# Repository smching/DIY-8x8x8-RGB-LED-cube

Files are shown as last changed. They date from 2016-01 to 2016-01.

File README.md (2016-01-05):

# DIY 8x8x8 RGB LED cube

DIY 8x8x8 RGB LED cube

Thank you my friend Siew Goh Chuang, he made this beautiful LED cube:  This is a 8x8x8 RGB LED cube project, a modified version of the LED cube which originally designed by Kavindarrah:

http://www.kevindarrah.com

This project only modified the hardware but leaving the software (source code) intact. All the source code is available in Kavindarrah's website.

Documentation is available at  http://ediy.com.my/index.php/projects/item/135-diy-8x8x8-rgb-led-cube

Flickr album: https://www.flickr.com/photos/ediy2u/albums/72157663117824245

Youtube video: https://youtu.be/O3SzMkJ8tPI

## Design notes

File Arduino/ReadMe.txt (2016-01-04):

**Arduino Code**

These Arduino code were written by Kevin Darrah: http://www.kevindarrah.com/?cat=99

Revision Notes:
Rev 7 ¨C First released code.  This is what you see running in the demo video, and all the tutorial videos

Rev 11 ¨C Fixed a bug in the Bit Angle Modulation, See the video How it Really Works for more information

Rev 12 ¨C Fixed the Bitwise Operation to set pins LOW.  I was doing it PORTX &= 0<<pinNumber, it should be PORTX &= ~(1<<pinNumber)  The wrong way was ANDing every pin in the port with 0, where is the new way ANDs only the pin you want to turn OFF with 0 and the rest with 1.

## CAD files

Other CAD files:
Layer building tool.dwg
RGB LED CUBE COVER.dwg

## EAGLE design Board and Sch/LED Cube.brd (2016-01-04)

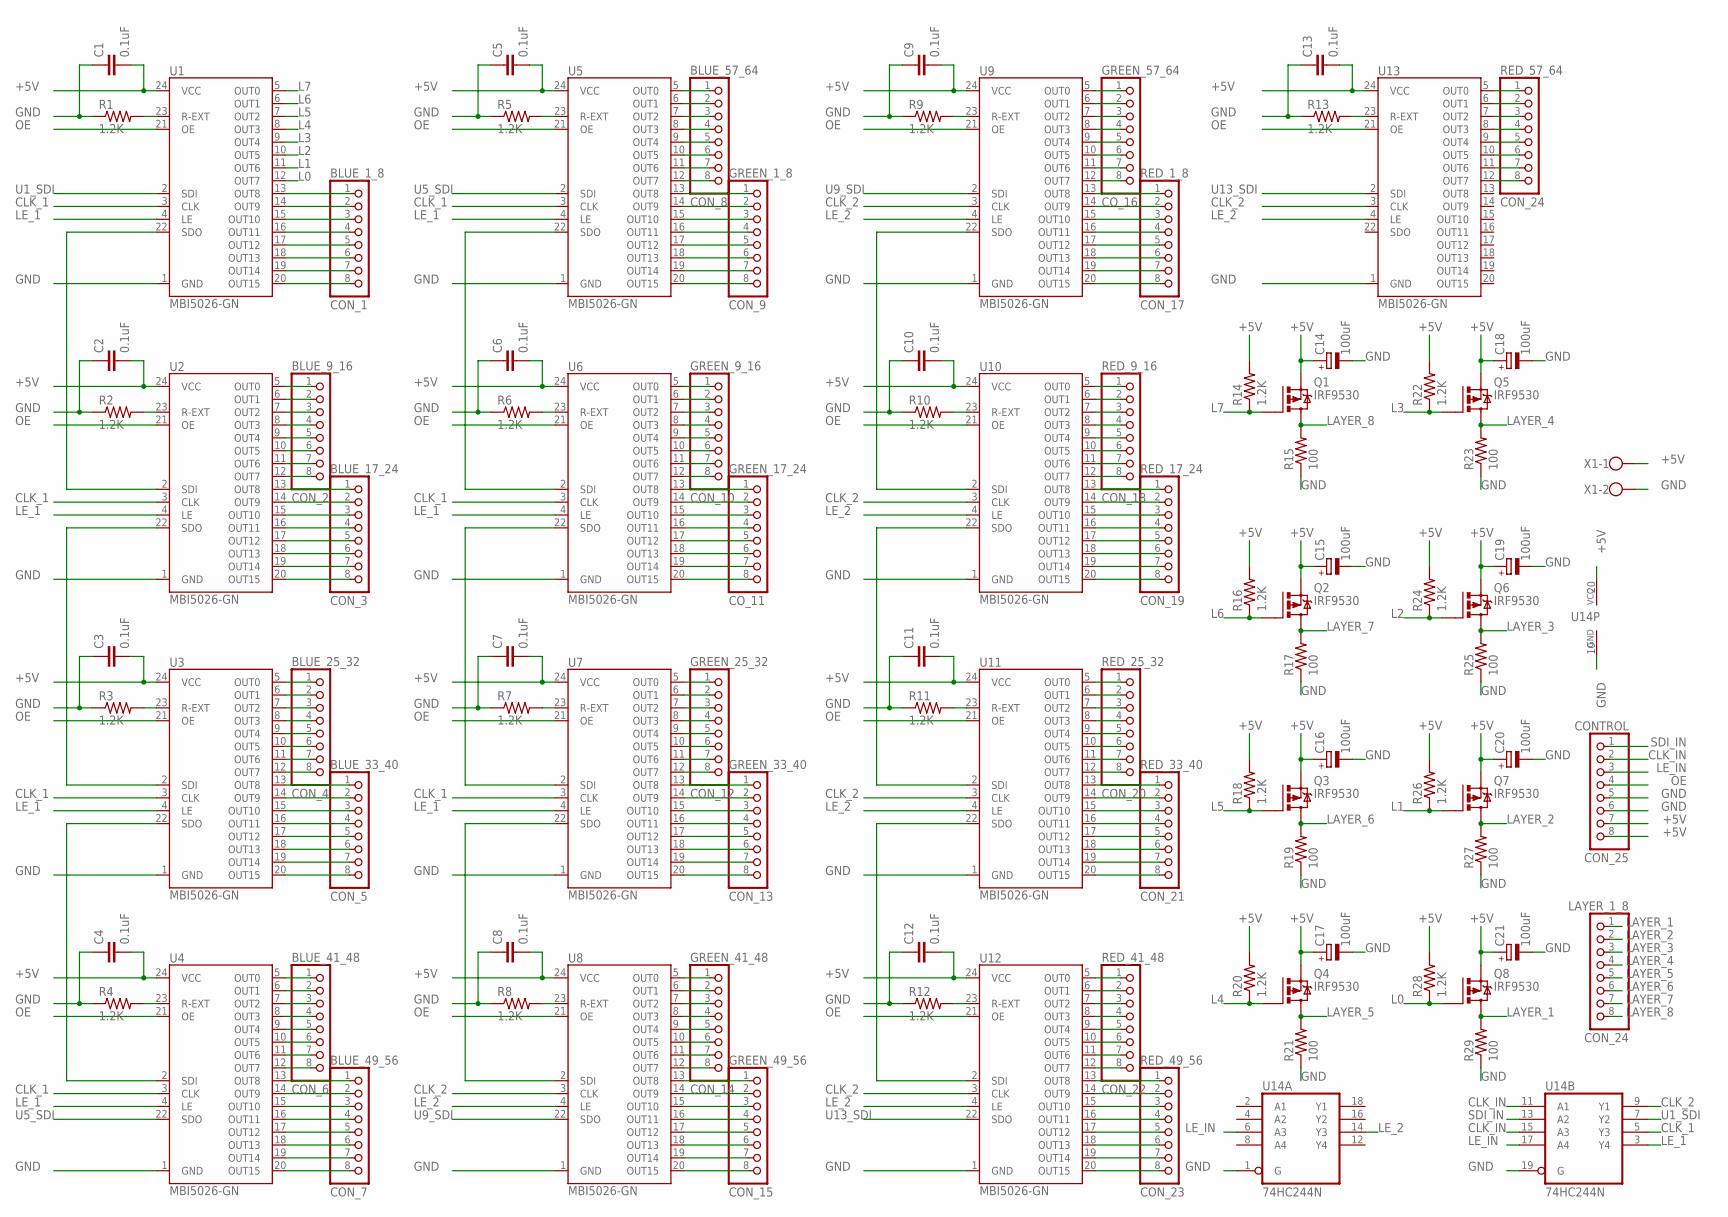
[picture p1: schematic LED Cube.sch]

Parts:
BLUE_1_8: CON_1; 1X08-BIG
BLUE_9_16: CON_2; 1X08-BIG
BLUE_17_24: CON_3; 1X08-BIG
BLUE_25_32: CON_4; 1X08-BIG
BLUE_33_40: CON_5; 1X08-BIG
BLUE_41_48: CON_6; 1X08-BIG
BLUE_49_56: CON_7; 1X08-BIG
BLUE_57_64: CON_8; 1X08-BIG
C1, C2, C3, C4, C5, C6, C7, C8, C9, C10, C11, C12, C13: 0.1uF; C2.5-3
C14, C15, C16, C17, C18, C19, C20, C21: 100uF; E5-6
CONTROL: CON_25; 1X08-BIG
GREEN_1_8: CON_9; 1X08-BIG
GREEN_9_16: CON_10; 1X08-BIG
GREEN_17_24: CO_11; 1X08-BIG
GREEN_25_32: CON_12; 1X08-BIG
GREEN_33_40: CON_13; 1X08-BIG
GREEN_41_48: CON_14; 1X08-BIG
GREEN_49_56: CON_15; 1X08-BIG
GREEN_57_64: CO_16; 1X08-BIG
LAYER_1_8: CON_24; 1X08-BIG
Q1, Q2, Q3, Q4, Q5, Q6, Q7, Q8: IRF9530; TO220BV
R1, R2, R3, R4, R5, R6, R7, R8, R9, R10, R11, R12, R13, R14, R16, R18, R20, R22, R24, R26, R28: 1.2K; 0207/15
R15, R17, R19, R21, R23, R25, R27, R29: 100; 0207/15
RED_1_8: CON_17; 1X08-BIG
RED_9_16: CON_18; 1X08-BIG
RED_17_24: CON_19; 1X08-BIG
RED_25_32: CON_20; 1X08-BIG
RED_33_40: CON_21; 1X08-BIG
RED_41_48: CON_22; 1X08-BIG
RED_49_56: CON_23; 1X08-BIG
RED_57_64: CON_24; 1X08-BIG
U1, U2, U3, U4, U5, U6, U7, U8, U9, U10, U11, U12, U13: MBI5026-GN; DIL24-3
U14: 74HC244N; DIL20
X1: W237-102

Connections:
+5V: C1.2, C2.2, C3.2, C4.2, C5.2, C6.2, C7.2, C8.2, C9.2, C10.2, C11.2, C12.2, C13.2, C14.+, C15.+, C16.+, C17.+, C18.+, C19.+, C20.+, C21.+, CONTROL.7, CONTROL.8, Q1.S, Q2.S, Q3.S, Q4.S, Q5.S, Q6.S, Q7.S, Q8.S, R14.2, R16.2, R18.2, R20.2, R22.2, R24.2, R26.2, R28.2, U1.24 (VCC), U2.24 (VCC), U3.24 (VCC), U4.24 (VCC), U5.24 (VCC), U6.24 (VCC), U7.24 (VCC), U8.24 (VCC), U9.24 (VCC), U10.24 (VCC), U11.24 (VCC), U12.24 (VCC), U13.24 (VCC), U14.20 (VCC), X1.1
CLK_1: U1.3 (CLK), U2.3 (CLK), U3.3 (CLK), U4.3 (CLK), U5.3 (CLK), U6.3 (CLK), U7.3 (CLK), U14.5 (Y3)
CLK_2: U8.3 (CLK), U9.3 (CLK), U10.3 (CLK), U11.3 (CLK), U12.3 (CLK), U13.3 (CLK), U14.9 (Y1)
CLK_IN: CONTROL.2, U14.11 (A1), U14.15 (A3)
GND: C1.1, C2.1, C3.1, C4.1, C5.1, C6.1, C7.1, C8.1, C9.1, C10.1, C11.1, C12.1, C13.1, C14.-, C15.-, C16.-, C17.-, C18.-, C19.-, C20.-, C21.-, CONTROL.5, CONTROL.6, R1.1, R2.1, R3.1, R4.1, R5.1, R6.1, R7.1, R8.1, R9.1, R10.1, R11.1, R12.1, R13.1, R15.1, R17.1, R19.1, R21.1, R23.1, R25.1, R27.1, R29.1, U1.1 (GND), U2.1 (GND), U3.1 (GND), U4.1 (GND), U5.1 (GND), U6.1 (GND), U7.1 (GND), U8.1 (GND), U9.1 (GND), U10.1 (GND), U11.1 (GND), U12.1 (GND), U13.1 (GND), U14.1 (G), U14.10 (GND), U14.19 (G), X1.2
L0: Q8.G, R28.1, U1.12 (OUT7)
L1: Q7.G, R26.1, U1.11 (OUT6)
L2: Q6.G, R24.1, U1.10 (OUT5)
L3: Q5.G, R22.1, U1.9 (OUT4)
L4: Q4.G, R20.1, U1.8 (OUT3)
L5: Q3.G, R18.1, U1.7 (OUT2)
L6: Q2.G, R16.1, U1.6 (OUT1)
L7: Q1.G, R14.1, U1.5 (OUT0)
LAYER_1: LAYER_1_8.1, Q8.D, R29.2
LAYER_2: LAYER_1_8.2, Q7.D, R27.2
LAYER_3: LAYER_1_8.3, Q6.D, R25.2
LAYER_4: LAYER_1_8.4, Q5.D, R23.2
LAYER_5: LAYER_1_8.5, Q4.D, R21.2
LAYER_6: LAYER_1_8.6, Q3.D, R19.2
LAYER_7: LAYER_1_8.7, Q2.D, R17.2
LAYER_8: LAYER_1_8.8, Q1.D, R15.2
LE_1: U1.4 (LE), U2.4 (LE), U3.4 (LE), U4.4 (LE), U5.4 (LE), U6.4 (LE), U7.4 (LE), U14.3 (Y4)
LE_2: U8.4 (LE), U9.4 (LE), U10.4 (LE), U11.4 (LE), U12.4 (LE), U13.4 (LE), U14.14 (Y3)
LE_IN: CONTROL.3, U14.6 (A3), U14.17 (A4)
unnamed: U1.22 (SDO), U2.2 (SDI)
unnamed: BLUE_1_8.1, U1.13 (OUT8)
unnamed: BLUE_1_8.2, U1.14 (OUT9)
unnamed: BLUE_1_8.3, U1.15 (OUT10)
unnamed: R2.2, U2.23 (R-EXT)
unnamed: U2.22 (SDO), U3.2 (SDI)
unnamed: BLUE_1_8.4, U1.16 (OUT11)
unnamed: BLUE_1_8.5, U1.17 (OUT12)
unnamed: BLUE_1_8.6, U1.18 (OUT13)
unnamed: R3.2, U3.23 (R-EXT)
unnamed: U3.22 (SDO), U4.2 (SDI)
unnamed: BLUE_1_8.7, U1.19 (OUT14)
unnamed: BLUE_1_8.8, U1.20 (OUT15)
unnamed: R4.2, U4.23 (R-EXT)
unnamed: BLUE_9_16.1, U2.5 (OUT0)
unnamed: BLUE_9_16.2, U2.6 (OUT1)
unnamed: BLUE_9_16.3, U2.7 (OUT2)
unnamed: R1.2, U1.23 (R-EXT)
unnamed: BLUE_9_16.4, U2.8 (OUT3)
unnamed: BLUE_9_16.5, U2.9 (OUT4)
unnamed: R5.2, U5.23 (R-EXT)
unnamed: U5.22 (SDO), U6.2 (SDI)
unnamed: BLUE_9_16.6, U2.10 (OUT5)
unnamed: BLUE_9_16.7, U2.11 (OUT6)
unnamed: R6.2, U6.23 (R-EXT)
unnamed: U6.22 (SDO), U7.2 (SDI)
unnamed: BLUE_9_16.8, U2.12 (OUT7)
unnamed: BLUE_17_24.1, U2.13 (OUT8)
unnamed: BLUE_17_24.2, U2.14 (OUT9)
unnamed: BLUE_17_24.3, U2.15 (OUT10)
unnamed: R7.2, U7.23 (R-EXT)
unnamed: U7.22 (SDO), U8.2 (SDI)
unnamed: BLUE_17_24.4, U2.16 (OUT11)
unnamed: BLUE_17_24.5, U2.17 (OUT12)
unnamed: R8.2, U8.23 (R-EXT)
unnamed: BLUE_17_24.6, U2.18 (OUT13)
unnamed: BLUE_17_24.7, U2.19 (OUT14)
unnamed: BLUE_17_24.8, U2.20 (OUT15)
unnamed: BLUE_25_32.1, U3.5 (OUT0)
unnamed: BLUE_25_32.2, U3.6 (OUT1)
unnamed: R9.2, U9.23 (R-EXT)
unnamed: U9.22 (SDO), U10.2 (SDI)
unnamed: BLUE_25_32.3, U3.7 (OUT2)
unnamed: BLUE_25_32.4, U3.8 (OUT3)
unnamed: R10.2, U10.23 (R-EXT)
unnamed: U10.22 (SDO), U11.2 (SDI)
unnamed: BLUE_25_32.5, U3.9 (OUT4)
unnamed: BLUE_25_32.6, U3.10 (OUT5)
unnamed: BLUE_25_32.7, U3.11 (OUT6)
unnamed: BLUE_25_32.8, U3.12 (OUT7)
unnamed: R11.2, U11.23 (R-EXT)
unnamed: U11.22 (SDO), U12.2 (SDI)
unnamed: BLUE_33_40.1, U3.13 (OUT8)
unnamed: BLUE_33_40.2, U3.14 (OUT9)
unnamed: R12.2, U12.23 (R-EXT)
unnamed: BLUE_33_40.3, U3.15 (OUT10)
unnamed: BLUE_33_40.4, U3.16 (OUT11)
unnamed: BLUE_33_40.5, U3.17 (OUT12)
unnamed: BLUE_33_40.6, U3.18 (OUT13)
unnamed: BLUE_33_40.7, U3.19 (OUT14)
unnamed: BLUE_33_40.8, U3.20 (OUT15)
unnamed: R13.2, U13.23 (R-EXT)
unnamed: BLUE_41_48.1, U4.5 (OUT0)
unnamed: BLUE_41_48.2, U4.6 (OUT1)
unnamed: BLUE_41_48.3, U4.7 (OUT2)
unnamed: BLUE_41_48.4, U4.8 (OUT3)
unnamed: BLUE_41_48.5, U4.9 (OUT4)
unnamed: BLUE_41_48.6, U4.10 (OUT5)
unnamed: BLUE_41_48.7, U4.11 (OUT6)
unnamed: BLUE_41_48.8, U4.12 (OUT7)
unnamed: BLUE_49_56.1, U4.13 (OUT8)
unnamed: BLUE_49_56.2, U4.14 (OUT9)
unnamed: BLUE_49_56.3, U4.15 (OUT10)
unnamed: BLUE_49_56.4, U4.16 (OUT11)
unnamed: BLUE_49_56.5, U4.17 (OUT12)
unnamed: BLUE_49_56.6, U4.18 (OUT13)
unnamed: BLUE_49_56.7, U4.19 (OUT14)
unnamed: BLUE_49_56.8, U4.20 (OUT15)
unnamed: BLUE_57_64.1, U5.5 (OUT0)
unnamed: BLUE_57_64.2, U5.6 (OUT1)
unnamed: BLUE_57_64.3, U5.7 (OUT2)
unnamed: BLUE_57_64.4, U5.8 (OUT3)
unnamed: BLUE_57_64.5, U5.9 (OUT4)
unnamed: BLUE_57_64.6, U5.10 (OUT5)
unnamed: BLUE_57_64.7, U5.11 (OUT6)
unnamed: BLUE_57_64.8, U5.12 (OUT7)
unnamed: GREEN_1_8.1, U5.13 (OUT8)
unnamed: GREEN_1_8.2, U5.14 (OUT9)
unnamed: GREEN_1_8.3, U5.15 (OUT10)
unnamed: GREEN_1_8.4, U5.16 (OUT11)
unnamed: GREEN_1_8.5, U5.17 (OUT12)
unnamed: GREEN_1_8.6, U5.18 (OUT13)
unnamed: GREEN_1_8.7, U5.19 (OUT14)
unnamed: GREEN_1_8.8, U5.20 (OUT15)
unnamed: GREEN_9_16.1, U6.5 (OUT0)
unnamed: GREEN_9_16.2, U6.6 (OUT1)
unnamed: GREEN_9_16.3, U6.7 (OUT2)
unnamed: GREEN_9_16.4, U6.8 (OUT3)
unnamed: GREEN_9_16.5, U6.9 (OUT4)
unnamed: GREEN_9_16.6, U6.10 (OUT5)
unnamed: GREEN_9_16.7, U6.11 (OUT6)
unnamed: GREEN_9_16.8, U6.12 (OUT7)
unnamed: GREEN_17_24.1, U6.13 (OUT8)
unnamed: GREEN_17_24.2, U6.14 (OUT9)
unnamed: GREEN_17_24.3, U6.15 (OUT10)
unnamed: GREEN_17_24.4, U6.16 (OUT11)
unnamed: GREEN_17_24.5, U6.17 (OUT12)
unnamed: GREEN_17_24.6, U6.18 (OUT13)
unnamed: GREEN_17_24.7, U6.19 (OUT14)
unnamed: GREEN_17_24.8, U6.20 (OUT15)
unnamed: GREEN_25_32.1, U7.5 (OUT0)
unnamed: GREEN_25_32.2, U7.6 (OUT1)
unnamed: GREEN_25_32.3, U7.7 (OUT2)
unnamed: GREEN_25_32.4, U7.8 (OUT3)
unnamed: GREEN_25_32.5, U7.9 (OUT4)
unnamed: GREEN_25_32.6, U7.10 (OUT5)
unnamed: GREEN_25_32.7, U7.11 (OUT6)
unnamed: GREEN_25_32.8, U7.12 (OUT7)
unnamed: GREEN_33_40.1, U7.13 (OUT8)
unnamed: GREEN_33_40.2, U7.14 (OUT9)
unnamed: GREEN_33_40.3, U7.15 (OUT10)
unnamed: GREEN_33_40.4, U7.16 (OUT11)
unnamed: GREEN_33_40.5, U7.17 (OUT12)
unnamed: GREEN_33_40.6, U7.18 (OUT13)
unnamed: GREEN_33_40.7, U7.19 (OUT14)
unnamed: GREEN_33_40.8, U7.20 (OUT15)
unnamed: GREEN_41_48.1, U8.5 (OUT0)
unnamed: GREEN_41_48.2, U8.6 (OUT1)
unnamed: GREEN_41_48.3, U8.7 (OUT2)
unnamed: GREEN_41_48.4, U8.8 (OUT3)
unnamed: GREEN_41_48.5, U8.9 (OUT4)
unnamed: GREEN_41_48.6, U8.10 (OUT5)
unnamed: GREEN_41_48.7, U8.11 (OUT6)
unnamed: GREEN_41_48.8, U8.12 (OUT7)
unnamed: GREEN_49_56.1, U8.13 (OUT8)
unnamed: GREEN_49_56.2, U8.14 (OUT9)
unnamed: GREEN_49_56.3, U8.15 (OUT10)
unnamed: GREEN_49_56.4, U8.16 (OUT11)
unnamed: GREEN_49_56.5, U8.17 (OUT12)
unnamed: GREEN_49_56.6, U8.18 (OUT13)
unnamed: GREEN_49_56.7, U8.19 (OUT14)
unnamed: GREEN_49_56.8, U8.20 (OUT15)
unnamed: GREEN_57_64.1, U9.5 (OUT0)
unnamed: GREEN_57_64.2, U9.6 (OUT1)
unnamed: GREEN_57_64.3, U9.7 (OUT2)
unnamed: GREEN_57_64.4, U9.8 (OUT3)
unnamed: GREEN_57_64.5, U9.9 (OUT4)
unnamed: GREEN_57_64.6, U9.10 (OUT5)
unnamed: GREEN_57_64.7, U9.11 (OUT6)
unnamed: GREEN_57_64.8, U9.12 (OUT7)
unnamed: RED_1_8.1, U9.13 (OUT8)
unnamed: RED_1_8.2, U9.14 (OUT9)
unnamed: RED_1_8.3, U9.15 (OUT10)
unnamed: RED_1_8.4, U9.16 (OUT11)
unnamed: RED_1_8.5, U9.17 (OUT12)
unnamed: RED_1_8.6, U9.18 (OUT13)
unnamed: RED_1_8.7, U9.19 (OUT14)
unnamed: RED_1_8.8, U9.20 (OUT15)
unnamed: RED_9_16.1, U10.5 (OUT0)
unnamed: RED_9_16.2, U10.6 (OUT1)
unnamed: RED_9_16.3, U10.7 (OUT2)
unnamed: RED_9_16.4, U10.8 (OUT3)
unnamed: RED_9_16.5, U10.9 (OUT4)
unnamed: RED_9_16.6, U10.10 (OUT5)
unnamed: RED_9_16.7, U10.11 (OUT6)
unnamed: RED_9_16.8, U10.12 (OUT7)
unnamed: RED_17_24.1, U10.13 (OUT8)
unnamed: RED_17_24.2, U10.14 (OUT9)
unnamed: RED_17_24.3, U10.15 (OUT10)
unnamed: RED_17_24.4, U10.16 (OUT11)
unnamed: RED_17_24.5, U10.17 (OUT12)
unnamed: RED_17_24.6, U10.18 (OUT13)
unnamed: RED_17_24.7, U10.19 (OUT14)
unnamed: RED_17_24.8, U10.20 (OUT15)
unnamed: RED_25_32.1, U11.5 (OUT0)
unnamed: RED_25_32.2, U11.6 (OUT1)
unnamed: RED_25_32.3, U11.7 (OUT2)
unnamed: RED_25_32.4, U11.8 (OUT3)
unnamed: RED_25_32.5, U11.9 (OUT4)
unnamed: RED_25_32.6, U11.10 (OUT5)
unnamed: RED_25_32.7, U11.11 (OUT6)
unnamed: RED_25_32.8, U11.12 (OUT7)
unnamed: RED_33_40.1, U11.13 (OUT8)
unnamed: RED_33_40.2, U11.14 (OUT9)
unnamed: RED_33_40.3, U11.15 (OUT10)
unnamed: RED_33_40.4, U11.16 (OUT11)
unnamed: RED_33_40.5, U11.17 (OUT12)
unnamed: RED_33_40.6, U11.18 (OUT13)
unnamed: RED_33_40.7, U11.19 (OUT14)
unnamed: RED_33_40.8, U11.20 (OUT15)
unnamed: RED_41_48.1, U12.5 (OUT0)
unnamed: RED_41_48.2, U12.6 (OUT1)
unnamed: RED_41_48.3, U12.7 (OUT2)
unnamed: RED_41_48.4, U12.8 (OUT3)
unnamed: RED_41_48.5, U12.9 (OUT4)
unnamed: RED_41_48.6, U12.10 (OUT5)
unnamed: RED_41_48.7, U12.11 (OUT6)
unnamed: RED_41_48.8, U12.12 (OUT7)
unnamed: RED_49_56.1, U12.13 (OUT8)
unnamed: RED_49_56.2, U12.14 (OUT9)
unnamed: RED_49_56.3, U12.15 (OUT10)
unnamed: RED_49_56.4, U12.16 (OUT11)
unnamed: RED_49_56.5, U12.17 (OUT12)
unnamed: RED_49_56.6, U12.18 (OUT13)
unnamed: RED_49_56.7, U12.19 (OUT14)
unnamed: RED_49_56.8, U12.20 (OUT15)
unnamed: RED_57_64.1, U13.5 (OUT0)
unnamed: RED_57_64.2, U13.6 (OUT1)
unnamed: RED_57_64.3, U13.7 (OUT2)
unnamed: RED_57_64.4, U13.8 (OUT3)
unnamed: RED_57_64.5, U13.9 (OUT4)
unnamed: RED_57_64.6, U13.10 (OUT5)
unnamed: RED_57_64.7, U13.11 (OUT6)
unnamed: RED_57_64.8, U13.12 (OUT7)
OE: CONTROL.4, U1.21 (OE), U2.21 (OE), U3.21 (OE), U4.21 (OE), U5.21 (OE), U6.21 (OE), U7.21 (OE), U8.21 (OE), U9.21 (OE), U10.21 (OE), U11.21 (OE), U12.21 (OE), U13.21 (OE)
SDI_IN: CONTROL.1, U14.13 (A2)
U1_SDI: U1.2 (SDI), U14.7 (Y2)
U5_SDI: U4.22 (SDO), U5.2 (SDI)
U9_SDI: U8.22 (SDO), U9.2 (SDI)
U13_SDI: U12.22 (SDO), U13.2 (SDI)

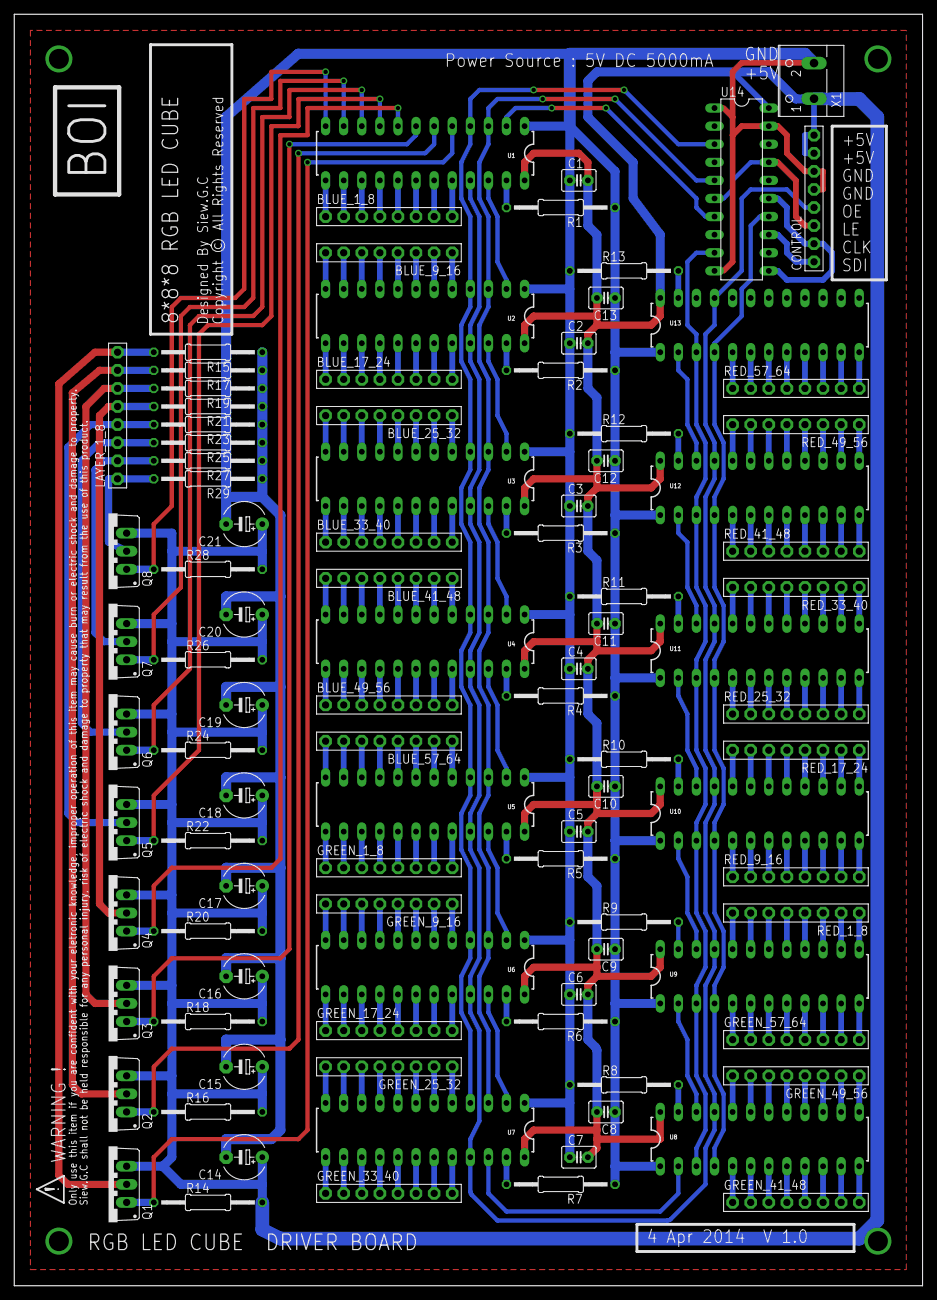
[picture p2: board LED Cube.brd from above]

Board: 2 copper layers, 127.5 x 178.5 mm, 99 parts (0 on the bottom side), 244 nets.

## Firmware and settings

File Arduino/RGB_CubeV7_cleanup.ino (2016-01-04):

/*
The 8x8x8 RGB LED Cube

by Kevin Darrah
www.kevindarrah.com

V7 01/24/2013

Disclaimer:
Not a professional LED cube builder, this is how I did it, and this is my cube
*/

#include <SPI.h>// SPI Library used to clock data out to the shift registers

#define latch_pin 2// can use any pin you want to latch the shift registers
#define blank_pin 4// same, can use any pin you want for this, just make sure you pull up via a 1k to 5V
#define data_pin 11// used by SPI, must be pin 11
#define clock_pin 13// used by SPI, must be 13

//***variables***variables***variables***variables***variables***variables***variables***variables
//These variables are used by multiplexing and Bit Angle Modulation Code
int shift_out;//used in the code a lot in for(i= type loops
byte anode[8];//byte to write to the anode shift register, 8 of them, shifting the ON level in each byte in the array

//This is how the brightness for every LED is stored,  
//Each LED only needs a 'bit' to know if it should be ON or OFF, so 64 Bytes gives you 512 bits= 512 LEDs
//Since we are modulating the LEDs, using 4 bit resolution, each color has 4 arrays containing 64 bits each
byte red0[64], red1[64], red2[64], red3[64];
byte blue0[64], blue1[64], blue2[64], blue3[64];
byte green0[64], green1[64], green2[64], green3[64];
//notice how more resolution will eat up more of your precious RAM

int level=0;//keeps track of which level we are shifting data to
int anodelevel=0;//this increments through the anode levels
int BAM_Bit, BAM_Counter=0; // Bit Angle Modulation variables to keep track of things

//These variables can be used for other things
unsigned long start;//for a millis timer to cycle through the animations

//****setup****setup****setup****setup****setup****setup****setup****setup****setup****setup****setup****setup****setup
void setup(){

SPI.setBitOrder(MSBFIRST);//Most Significant Bit First
SPI.setDataMode(SPI_MODE0);// Mode 0 Rising edge of data, keep clock low
SPI.setClockDivider(SPI_CLOCK_DIV2);//Run the data in at 16MHz/2 - 8MHz

//Serial.begin(115200);// if you need it?
noInterrupts();// kill interrupts until everybody is set up

//We use Timer 1 to refresh the cube
TCCR1A = B00000000;//Register A all 0's since we're not toggling any pins
TCCR1B = B00001011;//bit 3 set to place in CTC mode, will call an interrupt on a counter match
//bits 0 and 1 are set to divide the clock by 64, so 16MHz/64=250kHz
TIMSK1 = B00000010;//bit 1 set to call the interrupt on an OCR1A match
OCR1A=30; // you can play with this, but I set it to 30, which means:
//our clock runs at 250kHz, which is 1/250kHz = 4us
//with OCR1A set to 30, this means the interrupt will be called every (30+1)x4us=124us, 
// which gives a multiplex frequency of about 8kHz

// here I just set up the anode array, this is what's written to the anode shift register, to enable each level
anode[0]=B00000001;
anode[1]=B00000010;
anode[2]=B00000100;
anode[3]=B00001000;
anode[4]=B00010000;
anode[5]=B00100000;
anode[6]=B01000000;
anode[7]=B10000000;
// don't hate on how I assigned the values to this register! haha

//finally set up the Outputs
pinMode(latch_pin, OUTPUT);//Latch
pinMode(data_pin, OUTPUT);//MOSI DATA
pinMode(clock_pin, OUTPUT);//SPI Clock
pinMode(blank_pin, OUTPUT);//Output Enable  important to do this last, so LEDs do not flash on boot up
SPI.begin();//start up the SPI library
interrupts();//let the show begin, this lets the multiplexing start

}//***end setup***end setup***end setup***end setup***end setup***end setup***end setup***end setup***end setup***end setup


void loop(){//***start loop***start loop***start loop***start loop***start loop***start loop***start loop***start loop***start loop

//Each animation located in a sub routine
// To control an LED, you simply:
// LED(level you want 0-7, row you want 0-7, column you want 0-7, red brighness 0-15, green brighness 0-15, blue brighness 0-15);



rainVersionTwo();
folder();
sinwaveTwo();
wipe_out();
bouncyvTwo();
color_wheelTWO();

}//***end loop***end loop***end loop***end loop***end loop***end loop***end loop***end loop***end loop***end loop***end loop***end loop



void LED(int level, int row, int column, byte red, byte green, byte blue){ //****LED Routine****LED Routine****LED Routine****LED Routine
//This is where it all starts
//This routine is how LEDs are updated, with the inputs for the LED location and its R G and B brightness levels

// First, check and make sure nothing went beyond the limits, just clamp things at either 0 or 7 for location, and 0 or 15 for brightness
  if(level<0)
  level=0;
  if(level>7)
  level=7;
  if(row<0)
  row=0;
  if(row>7)
  row=7;
  if(column<0)
  column=0;
  if(column>7)
  column=7;  
    if(red<0)
  red=0;
  if(red>15)
  red=15;
  if(green<0)
  green=0;
  if(green>15)
  green=15;
  if(blue<0)
  blue=0;
  if(blue>15)
  blue=15;  
  
  
  //There are 512 LEDs in the cube, so when we write to level 2, column 5, row 4, that needs to be translated into a number from 0 to 511
  
  //This looks confusing, I know...
  int whichbyte = int(((level*64)+(row*8)+column)/8);
  
  // The first level LEDs are first in the sequence, then 2nd level, then third, and so on
  //the (level*64) is what indexes the level's starting place, so level 0 are LEDs 0-63, level 1 are LEDs 64-127, and so on
  
  //The column counts left to right 0-7 and the row is back to front 0-7
  //This means that if you had level 0, row 0, the bottom back row would count from 0-7, 
  
  //so if you looked down on the cube, and only looked at the bottom level
  // 00 01 02 03 04 05 06 07
  // 08 09 10 11 12 13 14 15
  // 16 17 18 19 20 21 22 23
  // 24 25 26 27 28 29 30 31
  // 32 33 34 35 36 37 38 39
  // 40 41 42 43 44 45 46 47  
  // 48 49 50 51 52 53 54 55  
  // 56 57 58 59 60 61 62 63

//Then, if you incremented the level, the top right of the grid above would start at 64
//The reason for doing this, is so you don't have to memorize a number for each LED, allowing you to use level, row, column

//Now, what about the divide by 8 in there?
//...well, we have 8 bits per byte, and we have 64 bytes in memory for all 512 bits needed for each LED, so
//we divide the number we just found by 8, and take the integ7er of it, so we know which byte, that bit is located
//confused? that's ok, let's take an example, if we wanted to write to the LED to the last LED in the cube, we would write a 7, 7, 7
// giving (7*64)+(7*8)=7 = 511, which is right, but now let's divide it by 8, 511/8 = 63.875, and take the int of it so, we get 63,
//this is the last byte in the array, which is right since this is the last LED
  
// This next variable is the same thing as before, but here we don't divide by 8, so we get the LED number 0-511
  int wholebyte=(level*64)+(row*8)+column;
//This will all make sense in a sec
 
 //This is 4 bit color resolution, so each color contains x4 64 byte arrays, explanation below:
  bitWrite(red0[whichbyte], wholebyte-(8*whichbyte), bitRead(red, 0));
  bitWrite(red1[whichbyte], wholebyte-(8*whichbyte), bitRead(red, 1));
  bitWrite(red2[whichbyte], wholebyte-(8*whichbyte), bitRead(red, 2)); 
  bitWrite(red3[whichbyte], wholebyte-(8*whichbyte), bitRead(red, 3)); 

  bitWrite(green0[whichbyte], wholebyte-(8*whichbyte), bitRead(green, 0));
  bitWrite(green1[whichbyte], wholebyte-(8*whichbyte), bitRead(green, 1));
  bitWrite(green2[whichbyte], wholebyte-(8*whichbyte), bitRead(green, 2)); 
  bitWrite(green3[whichbyte], wholebyte-(8*whichbyte), bitRead(green, 3));

  bitWrite(blue0[whichbyte], wholebyte-(8*whichbyte), bitRead(blue, 0));
  bitWrite(blue1[whichbyte], wholebyte-(8*whichbyte), bitRead(blue, 1));
  bitWrite(blue2[whichbyte], wholebyte-(8*whichbyte), bitRead(blue, 2)); 
  bitWrite(blue3[whichbyte], wholebyte-(8*whichbyte), bitRead(blue, 3));
  
//Are you now more confused?  You shouldn't be!  It's starting to make sense now.  Notice how each line is a bitWrite, which is,
//bitWrite(the byte you want to write to, the bit of the byte to write, and the 0 or 1 you want to write)
//This means that the 'whichbyte' is the byte from 0-63 in which the bit corresponding to the LED from 0-511
//Is making sense now why we did that? taking a value from 0-511 and converting it to a value from 0-63, since each LED represents a bit in 
//an array of 64 bytes.
//Then next line is which bit 'wholebyte-(8*whichbyte)'  
//This is simply taking the LED's value of 0-511 and subracting it from the BYTE its bit was located in times 8
//Think about it, byte 63 will contain LEDs from 504 to 511, so if you took 505-(8*63), you get a 1, meaning that,
//LED number 505 is is located in bit 1 of byte 63 in the array

//is that it?  No, you still have to do the bitRead of the brightness 0-15 you are trying to write,
//if you wrote a 15 to RED, all 4 arrays for that LED would have a 1 for that bit, meaning it will be on 100%
//This is why the four arrays read 0-4 of the value entered in for RED, GREEN, and BLUE
//hopefully this all makes some sense?

}//****LED routine end****LED routine end****LED routine end****LED routine end****LED routine end****LED routine end****LED routine end

ISR(TIMER1_COMPA_vect){//***MultiPlex BAM***MultiPlex BAM***MultiPlex BAM***MultiPlex BAM***MultiPlex BAM***MultiPlex BAM***MultiPlex BAM

//This routine is called in the background automatically at frequency set by OCR1A
//In this code, I set OCR1A to 30, so this is called every 124us, giving each level in the cube 124us of ON time
//There are 8 levels, so we have a maximum brightness of 1/8, since the level must turn off before the next level is turned on
//The frequency of the multiplexing is then 124us*8=992us, or 1/992us= about 1kHz


  PORTD |= 1<<blank_pin;//The first thing we do is turn all of the LEDs OFF, by writing a 1 to the blank pin
  //Note, in my bread-boarded version, I was able to move this way down in the cube, meaning that the OFF time was minimized
  //do to signal integrity and parasitic capcitance, my rise/fall times, required all of the LEDs to first turn off, before updating
  //otherwise you get a ghosting effect on the previous level

//This is 4 bit 'Bit angle Modulation' or BAM, There are 8 levels, so when a '1' is written to the color brightness, 
//each level will have a chance to light up for 1 cycle, the BAM bit keeps track of which bit we are modulating out of the 4 bits
//Bam counter is the cycle count, meaning as we light up each level, we increment the BAM_Counter
if(BAM_Counter==8)
BAM_Bit++;
else
if(BAM_Counter==16)
BAM_Bit++;
else
if(BAM_Counter==32)
BAM_Bit++;

BAM_Counter++;//Here is where we increment the BAM counter

switch (BAM_Bit){//The BAM bit will be a value from 0-3, and only shift out the arrays corresponding to that bit, 0-3
//Here's how this works, each case is the bit in the Bit angle modulation from 0-4, 
//Next, it depends on which level we're on, so the byte in the array to be written depends on which level, but since each level contains 64 LED,
//we only shift out 8 bytes for each color
case 0:
 for(shift_out=level; shift_out<level+8; shift_out++)
 SPI.transfer(red0[shift_out]);
 for(shift_out=level; shift_out<level+8; shift_out++)
 SPI.transfer(green0[shift_out]); 
 for(shift_out=level; shift_out<level+8; shift_out++)
 SPI.transfer(blue0[shift_out]);
  break;
case 1:
 for(shift_out=level; shift_out<level+8; shift_out++)
 SPI.transfer(red1[shift_out]);
 for(shift_out=level; shift_out<level+8; shift_out++)
 SPI.transfer(green1[shift_out]); 
 for(shift_out=level; shift_out<level+8; shift_out++)
 SPI.transfer(blue1[shift_out]);
  break;
 case 2:
 for(shift_out=level; shift_out<level+8; shift_out++)
 SPI.transfer(red2[shift_out]);
 for(shift_out=level; shift_out<level+8; shift_out++)
 SPI.transfer(green2[shift_out]); 
 for(shift_out=level; shift_out<level+8; shift_out++)
 SPI.transfer(blue2[shift_out]);
 break;
 case 3:
 for(shift_out=level; shift_out<level+8; shift_out++)
 SPI.transfer(red3[shift_out]);
 for(shift_out=level; shift_out<level+8; shift_out++)
 SPI.transfer(green3[shift_out]); 
 for(shift_out=level; shift_out<level+8; shift_out++)
 SPI.transfer(blue3[shift_out]);
 //Here is where the BAM_Counter is reset back to 0, it's only 4 bit, but since each cycle takes 8 counts,
 //, it goes 0 8 16 32, and when BAM_counter hits 64 we reset the BAM
  if(BAM_Counter==64){
  BAM_Counter=0;
  BAM_Bit=0;
  }
  break;
}//switch_case

SPI.transfer(anode[anodelevel]);//finally, send out the anode level byte

PORTD |= 1<<latch_pin;//Latch pin HIGH
PORTD &= 0<<latch_pin;//Latch pin LOW
PORTD &= 0<<blank_pin;//Blank pin LOW to turn on the LEDs with the new data

anodelevel++;//inrement the anode level
level = level+8;//increment the level variable by 8, which is used to shift out data, since the next level woudl be the next 8 bytes in the arrays

if(anodelevel==8)//go back to 0 if max is reached
anodelevel=0;
if(level==64)//if you hit 64 on level, this means you just sent out all 63 bytes, so go back
level=0;
}//***MultiPlex BAM END***MultiPlex BAM END***MultiPlex BAM END***MultiPlex BAM END***MultiPlex BAM END***MultiPlex BAM END***MultiPlex BAM END



//*+*+*+*+*+*+*+*+*+*+*+*+PUT ANIMATIONS DOWN HERE*+*+*+*+*+*+*+*+*+*+*+*+PUT ANIMATIONS DOWN HERE*+*+*+*+*+*+*+*+*+*+*+*+PUT ANIMATIONS DOWN HERE
//*+*+*+*+*+*+*+*+*+*+*+*+PUT ANIMATIONS DOWN HERE*+*+*+*+*+*+*+*+*+*+*+*+PUT ANIMATIONS DOWN HERE*+*+*+*+*+*+*+*+*+*+*+*+PUT ANIMATIONS DOWN HERE
//*+*+*+*+*+*+*+*+*+*+*+*+PUT ANIMATIONS DOWN HERE*+*+*+*+*+*+*+*+*+*+*+*+PUT ANIMATIONS DOWN HERE*+*+*+*+*+*+*+*+*+*+*+*+PUT ANIMATIONS DOWN HERE
//*+*+*+*+*+*+*+*+*+*+*+*+PUT ANIMATIONS DOWN HERE*+*+*+*+*+*+*+*+*+*+*+*+PUT ANIMATIONS DOWN HERE*+*+*+*+*+*+*+*+*+*+*+*+PUT ANIMATIONS DOWN HERE

void wipe_out(){//*****wipe_out*****wipe_out*****wipe_out*****wipe_out*****wipe_out*****wipe_out*****wipe_out*****wipe_out
  int xxx=0, yyy=0, zzz=0;
  int fx=random(8), fy=random(8), fz=random(8), direct, fxm=1, fym=1, fzm=1, fxo=0, fyo=0, fzo=0;
  int  ftx=random(8), fty=random(8), ftz=random(8), ftxm=1, ftym=1, ftzm=1, ftxo=0, ftyo=0, ftzo=0;
  int select, rr, gg, bb, rrt, ggt, bbt;
  for(xxx=0; xxx<8; xxx++){
  for(yyy=0; yyy<8; yyy++){
  for(zzz=0; zzz<8; zzz++){
  LED(xxx, yyy, zzz, 0, 0, 0);
  }}}
  
       select=random(3);
    if(select==0){
      rr=random(1, 16);
      gg=random(1, 16);
      bb=0;} 
     if(select==1){
      rr=random(1, 16);
      gg=0;
      bb=random(1, 16);}    
     if(select==2){
      rr=0;
      gg=random(1, 16);
      bb=random(1, 16);}
      
       select=random(3);
    if(select==0){
      rrt=random(1, 16);
      ggt=random(1, 16);
      bbt=0;} 
     if(select==1){
      rrt=random(1, 16);
      ggt=0;
      bbt=random(1, 16);}    
     if(select==2){
      rrt=0;
      ggt=random(1, 16);
      bbt=random(1, 16);}  
        start=millis();
      
  while(millis()-start<10000){
  
    //fx=random(8); fy=random(8); fz=random(8);

    LED(fxo, fyo, fzo, 0, 0, 0);
    LED(fxo, fyo, fzo+1, 0, 0, 0);
    LED(fxo, fyo, fzo-1, 0, 0, 0);
    LED(fxo+1, fyo, fzo, 0, 0, 0);
    LED(fxo-1, fyo, fzo, 0, 0, 0);
    LED(fxo, fyo+1, fzo, 0, 0, 0);
    LED(fxo, fyo-1, fzo, 0, 0, 0);
    
    LED(ftxo, ftyo, ftzo, 0, 0, 0);
    LED(ftxo, ftyo, ftzo+1, 0, 0, 0);
    LED(ftxo, ftyo, ftzo-1, 0, 0, 0);
    LED(ftxo+1, ftyo, ftzo, 0, 0, 0);
    LED(ftxo-1, ftyo, ftzo, 0, 0, 0);
    LED(ftxo, ftyo+1, ftzo, 0, 0, 0);
    LED(ftxo, ftyo-1, ftzo, 0, 0, 0);

    LED(ftx, fty, ftz, rr, gg, bb);
    LED(ftx, fty, ftz+1, rr, gg, bb);
    LED(ftx, fty, ftz-1,  rr, gg, bb);
    LED(ftx+1, fty, ftz, rr, gg, bb);
    LED(ftx-1, fty, ftz, rr, gg, bb);
    LED(ftx, fty+1, ftz, rr, gg, bb);
    LED(ftx, fty-1, ftz, rr, gg, bb);     
    
    LED(fx, fy, fz, rrt, ggt, bbt);
    LED(fx, fy, fz+1, rrt, ggt, bbt);
    LED(fx, fy, fz-1, rrt, ggt, bbt);
    LED(fx+1, fy, fz, rrt, ggt, bbt);
    LED(fx-1, fy, fz, rrt, ggt, bbt);
    LED(fx, fy+1, fz, rrt, ggt, bbt);
    LED(fx, fy-1, fz, rrt, ggt, bbt);  
    
    
     delay(10);
     
    fxo=fx;
    fyo=fy;
    fzo=fz; 
    
    ftxo=ftx;
    ftyo=fty;
    ftzo=ftz; 
 
    direct=random(3);
    if(direct==0)
    fx= fx+fxm;
    if(direct==1)
    fy= fy+fym;  
    if(direct==2)
    fz= fz+fzm;  
  if(fx<0){
    fx=0; fxm=1;}
  if(fx>7){
    fx=7; fxm=-1;}  
  if(fy<0){
    fy=0; fym=1;}
  if(fy>7){
    fy=7; fym=-1;}    
  if(fz<0){
    fz=0; fzm=1;}
  if(fz>7){
    fz=7; fzm=-1;}  
  
      direct=random(3);
    if(direct==0)
    ftx= ftx+ftxm;
    if(direct==1)
    fty= fty+ftym;  
    if(direct==2)
    ftz= ftz+ftzm;  
  if(ftx<0){
    ftx=0; ftxm=1;}
  if(ftx>7){
    ftx=7; ftxm=-1;}  
  if(fty<0){
    fty=0; ftym=1;}
  if(fty>7){
    fty=7; ftym=-1;}    
  if(ftz<0){
    ftz=0; ftzm=1;}
  if(ftz>7){
    ftz=7; ftzm=-1;} 
  }//while
    for(xxx=0; xxx<8; xxx++){
  for(yyy=0; yyy<8; yyy++){
  for(zzz=0; zzz<8; zzz++){
  LED(xxx, yyy, zzz, 0, 0, 0);
  }}}
  
}//wipeout


void rainVersionTwo(){//****rainVersionTwo****rainVersionTwo****rainVersionTwo****rainVersionTwo****rainVersionTwo
  int x[64], y[64], z[64], addr, leds=64, bright=1, ledcolor, colowheel;
  int xx[64], yy[64], zz[64], xold[64], yold[64], zold[64], slowdown;
  
  for(addr=0; addr<64; addr++){
    x[addr]=random(8);
    y[addr]=random(8);
    z[addr]=random(8);
    xx[addr]=random(16);
    yy[addr]=random(16);
    zz[addr]=random(16);     
  }
  start=millis();
  while(millis()-start<20000){
  //wipe_out();
  //for(addr=0; addr<leds; addr++)
  //LED(zold[addr], xold[addr], yold[addr], 0, 0, 0);
  
if(ledcolor<200){
  for(addr=0; addr<leds; addr++){
    LED(zold[addr], xold[addr], yold[addr], 0, 0, 0);
  if(z[addr]>=7)
  LED(z[addr], x[addr], y[addr], 0, 5, 15);
  if(z[addr]==6)
  LED(z[addr], x[addr], y[addr], 0, 1, 9);
   if(z[addr]==5)
  LED(z[addr], x[addr], y[addr], 0, 0, 10);
   if(z[addr]==4)
  LED(z[addr], x[addr], y[addr], 1, 0, 11); 
    if(z[addr]==3)
  LED(z[addr], x[addr], y[addr], 3, 0, 12);
    if(z[addr]==2)
  LED(z[addr], x[addr], y[addr], 10, 0, 15);
    if(z[addr]==1)
  LED(z[addr], x[addr], y[addr], 10, 0, 10);
    if(z[addr]<=0)
  LED(z[addr], x[addr], y[addr], 10, 0, 1);
}}//200

  if(ledcolor>=200&&ledcolor<300){
  for(addr=0; addr<leds; addr++){
    LED(zold[addr], xold[addr], yold[addr], 0, 0, 0);
  if(z[addr]>=7)
  LED(z[addr], x[addr], y[addr], 15, 15, 0);
  if(z[addr]==6)
  LED(z[addr], x[addr], y[addr], 10, 10, 0);
   if(z[addr]==5)
  LED(z[addr], x[addr], y[addr], 15, 5, 0);
   if(z[addr]==4)
  LED(z[addr], x[addr], y[addr], 15, 2, 0); 
    if(z[addr]==3)
  LED(z[addr], x[addr], y[addr], 15, 1, 0);
    if(z[addr]==2)
  LED(z[addr], x[addr], y[addr], 15, 0, 0);
    if(z[addr]==1)
  LED(z[addr], x[addr], y[addr], 12, 0, 0);
    if(z[addr]<=0)
  LED(z[addr], x[addr], y[addr], 10, 0, 0);
}}//300

    if(ledcolor>=300&&ledcolor<400){

  }
     if(ledcolor>=500&&ledcolor<600){

}
  
  
  ledcolor++;
if(ledcolor>=300)
ledcolor=0;
  
    for(addr=0; addr<leds; addr++){
    xold[addr]=x[addr];
    yold[addr]=y[addr];
    zold[addr]=z[addr];
   } 
  
  
  delay(15);
  
  //for(addr=0; addr<leds; addr++)
  //LED(z[addr], x[addr], y[addr], 0, 0, 0);
    for(addr=0; addr<leds; addr++){
      
      //slowdown = random(2);
      //if(bitRead(z[addr],0))
  z[addr] = z[addr]-1;
  
 // x[addr] = x[addr]+1;
 // y[addr] = y[addr]+1;
  if(z[addr]<random(-100,0)){
    x[addr]=random(8);
    y[addr]=random(8);
    int select=random(3);
    if(select==0){
    xx[addr]=0;
    zz[addr]=random(16);
    yy[addr]=random(16);
    //zz[addr]=0;
    }
    if(select==1){
    xx[addr]=random(16);
    zz[addr]=0;
    yy[addr]=random(16);
    //yy[addr]=0;
    }
    if(select==2){
    xx[addr]=random(16);
    zz[addr]=random(16);
    yy[addr]=0;
    
    
    }    
   z[addr]=7; 
   
  }//-check
  }//add

  
  }//while
 
}//rainv2
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

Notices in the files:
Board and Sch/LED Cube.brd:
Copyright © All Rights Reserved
